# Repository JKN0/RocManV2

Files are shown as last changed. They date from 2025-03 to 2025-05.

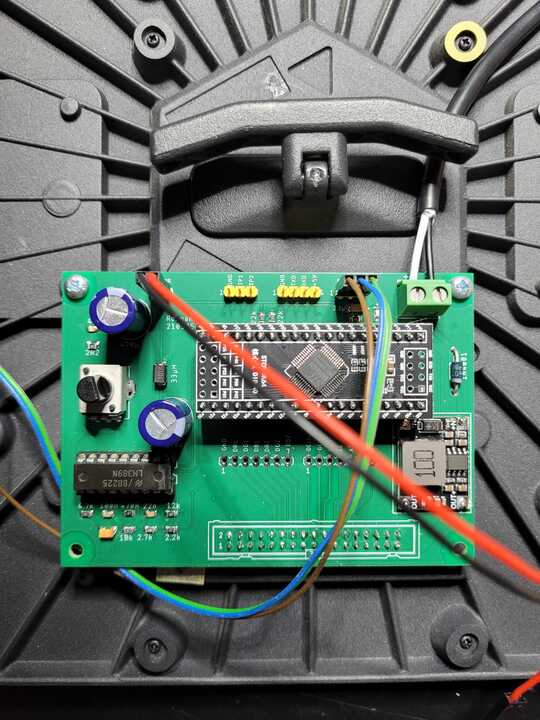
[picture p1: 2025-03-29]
RocManV2_PCB.jpg

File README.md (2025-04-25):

# RocMan V2

A Pacman game built using a junk RGB led matrix, 88x88 pixels

Controlled by junk IR remote

CPU is Chinese 8051 variant STC8A8K64D4

This is built on PCB, minor I/O-pin changes in SW compared to V1

There are two versions of PCB:
 - V2.0: original PCB
 - V2.1: connectors for USB/serial adapter and analog joystick added
 
Software is the same for both PCBs.

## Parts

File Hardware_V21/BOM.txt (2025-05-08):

Qty Value              Device             Package         Parts                Description                          
1   STC8A8K64D4-BRKOUT STC8A8K64D4-BRKOUT DIL40           IC1                  STC8A8K64D4/QFP48 @ DIP-40 breakout  
1                      LM389              DIL18           IC2                  Audio amp + 3 transistors            
1   1N4001             1N4004             DO41-10         D1                   DIODE
1   1N4148             1N4148             SOD-123         D2                   DIODE
1                      LEDCHIP-LED0805    CHIP-LED0805    LED1                 LED                                  0603
1                      ML34               ML34            CN1                  PIN HEADER FEMALE 2x17               
1                      MA04-1             MA04-1          CN2                  PIN HEADER 1x4                       
2                      MA03-1             MA03-1          CN3, CN4             PIN HEADER 1x3                       
1                      PINHD-1X2          1X02            CN5                  PIN HEADER 1x2                       
2                                                                              PIN HEADER FEMALE 1x20 (for IC1)     
1                      W237-02P           W237-132        CN6                  SREW CLAMP                           
2                      MA07-1             MA07-1          CN7, CN8             PIN HEADER 1x7                       
1                      MA06-1             MA06-1          CN9                  PIN HEADER 1x6                       
1                      MA05-1             MA05-1          CN10                 PIN HEADER 1x5                       
1   100n               C-EUC0805          C0805           C1                   CAPACITOR                            
1   22n                C-EUC0805          C0805           C2                   CAPACITOR                            
2   470μ               CPOL-EUE5-10.5     E5-10,5         C3, C4               POLARIZED CAPACITOR                  
1   2.2μ               CPOL-EUSMCA        SMC_A           C5                   POLARIZED CAPACITOR                  
1   1μ                 CPOL-EUSMCA        SMC_A           C6                   POLARIZED CAPACITOR                  
1   47n                C-EUC0805          C0805           C7                   CAPACITOR                            0603
1   10μ                CPOL-EUSMCA        SMC_A           C8                   POLARIZED CAPACITOR                  use 4.7μ
1   10k                R-EU_R0805         R0805           R1                   RESISTOR                             
1   2.7k               R-EU_R0805         R0805           R2                   RESISTOR                             
1   12k                R-EU_R0805         R0805           R3                   RESISTOR                             
1   4.7k               R-EU_R0805         R0805           R4                   RESISTOR                             
1   1k                 R-EU_R0805         R0805           R7                   RESISTOR                             
1   2R2                R-EU_R0805         R0805           R5                   RESISTOR                             
1   470R               R-EU_R0805         R0805           R6                   RESISTOR                             
1   2.2k               R-EU_R0805         R0805           R8                   RESISTOR                             
2   22k                R-EU_R0805         R0805           R9, R10              RESISTOR
1   100R               R-EU_R0805         R0805           R11                  RESISTOR                             
1   10k                PTV09A-4015F-A103  PTV09A4015FA103 VR1                  Pot 10K AUDIO 20%                    
1   33μH               L-USL4532C         L4532M          L1                   INDUCTOR                     100μH works also
1                      Pwr supply module                                       Pwr 9...24V/5V                       
1   TSOP34838          IR receiver                                                                                  
1                      18-pin IC socket                                        Socket for IC2
1   PCB

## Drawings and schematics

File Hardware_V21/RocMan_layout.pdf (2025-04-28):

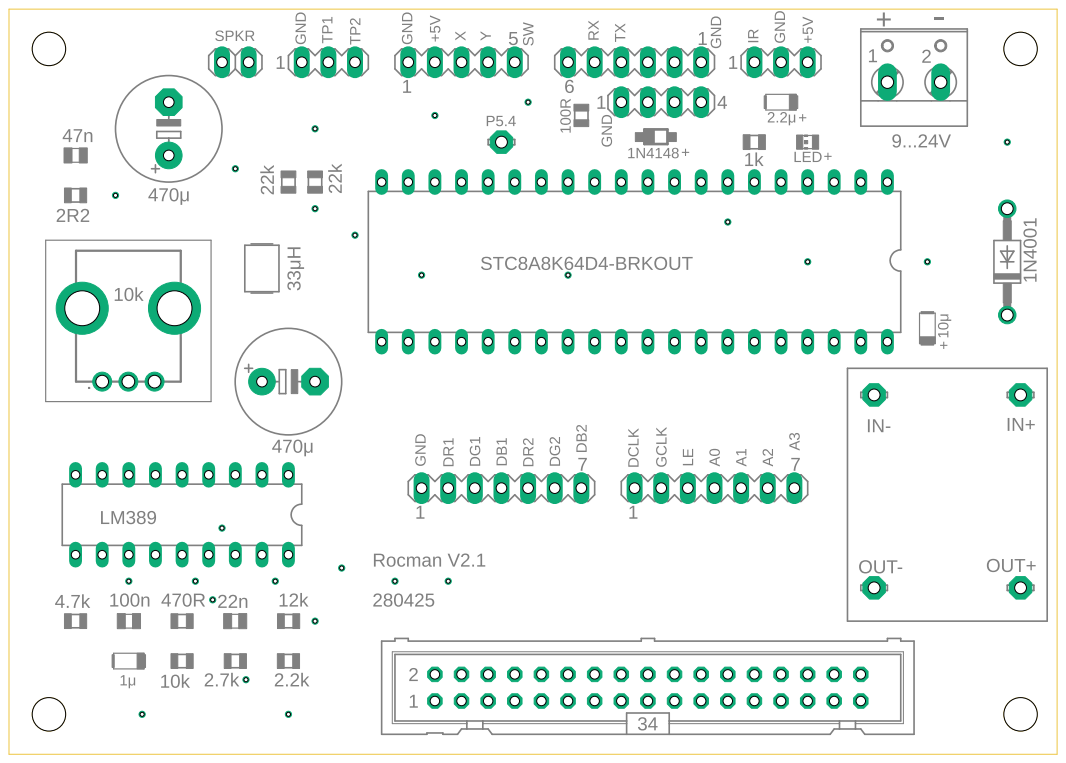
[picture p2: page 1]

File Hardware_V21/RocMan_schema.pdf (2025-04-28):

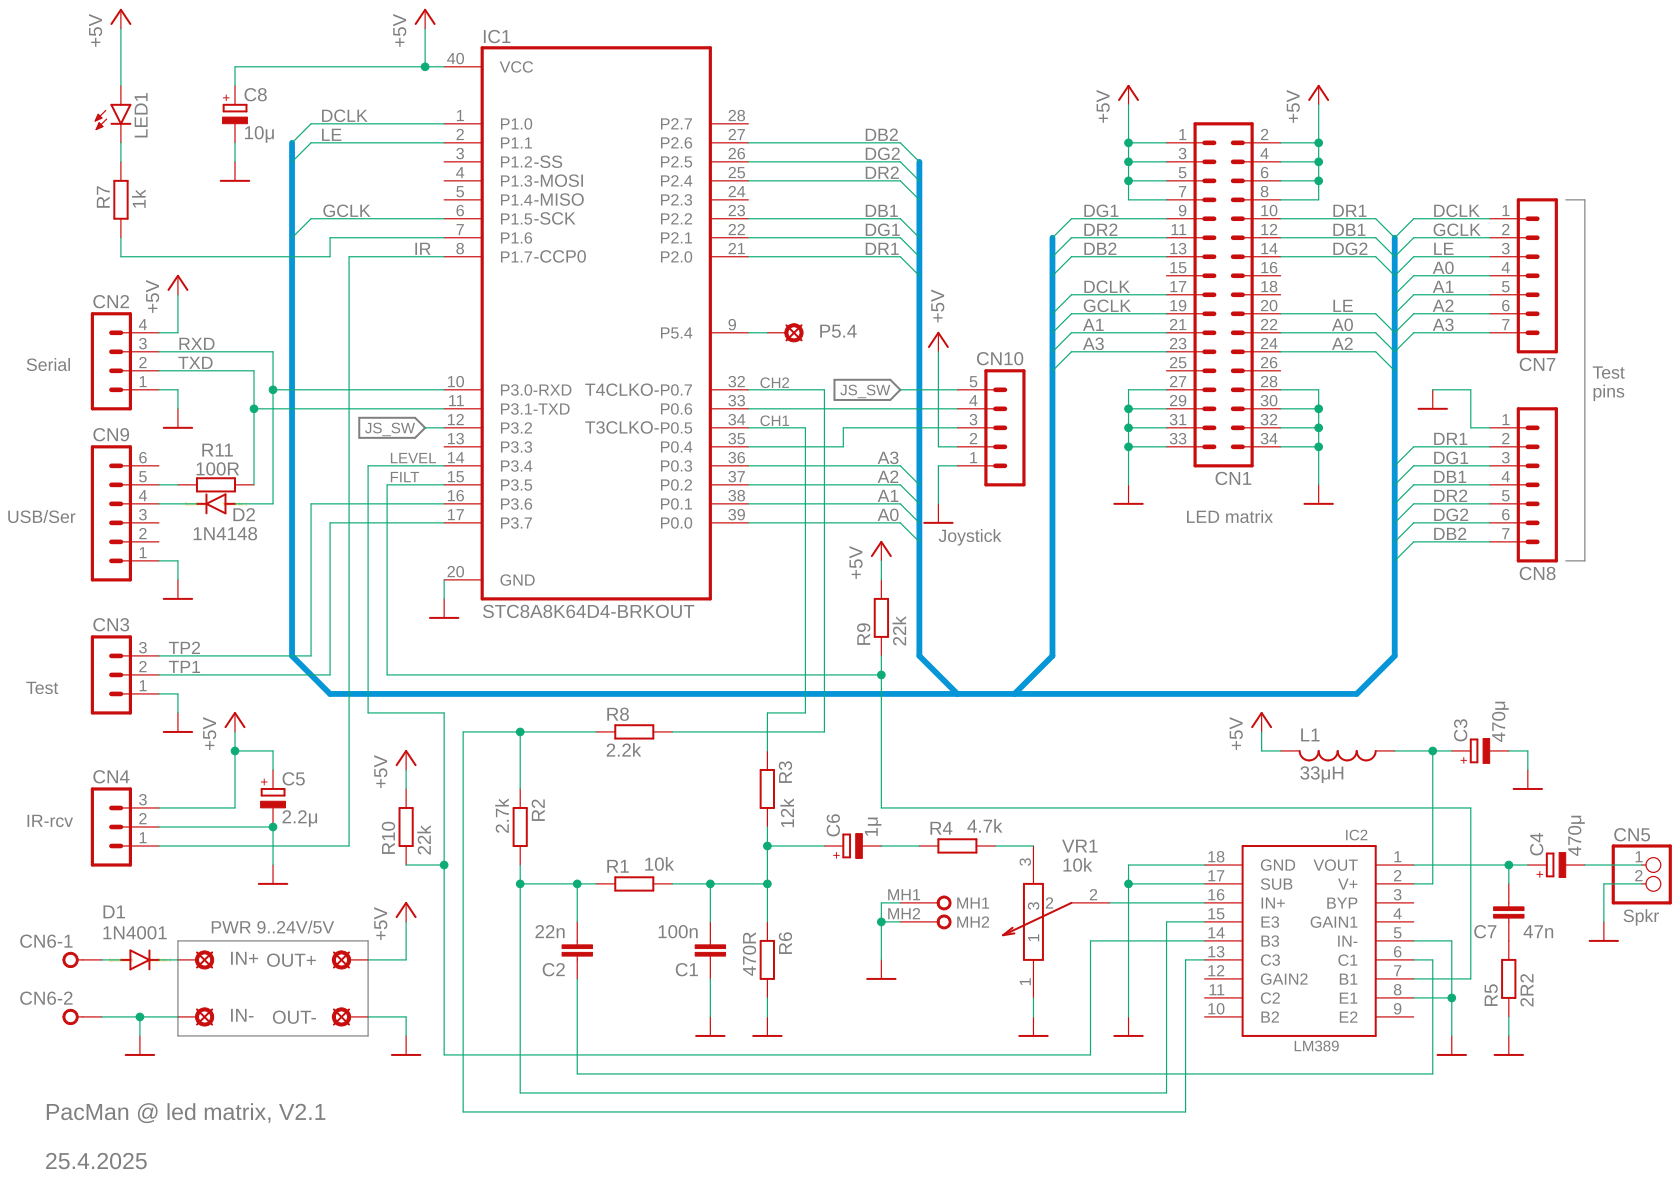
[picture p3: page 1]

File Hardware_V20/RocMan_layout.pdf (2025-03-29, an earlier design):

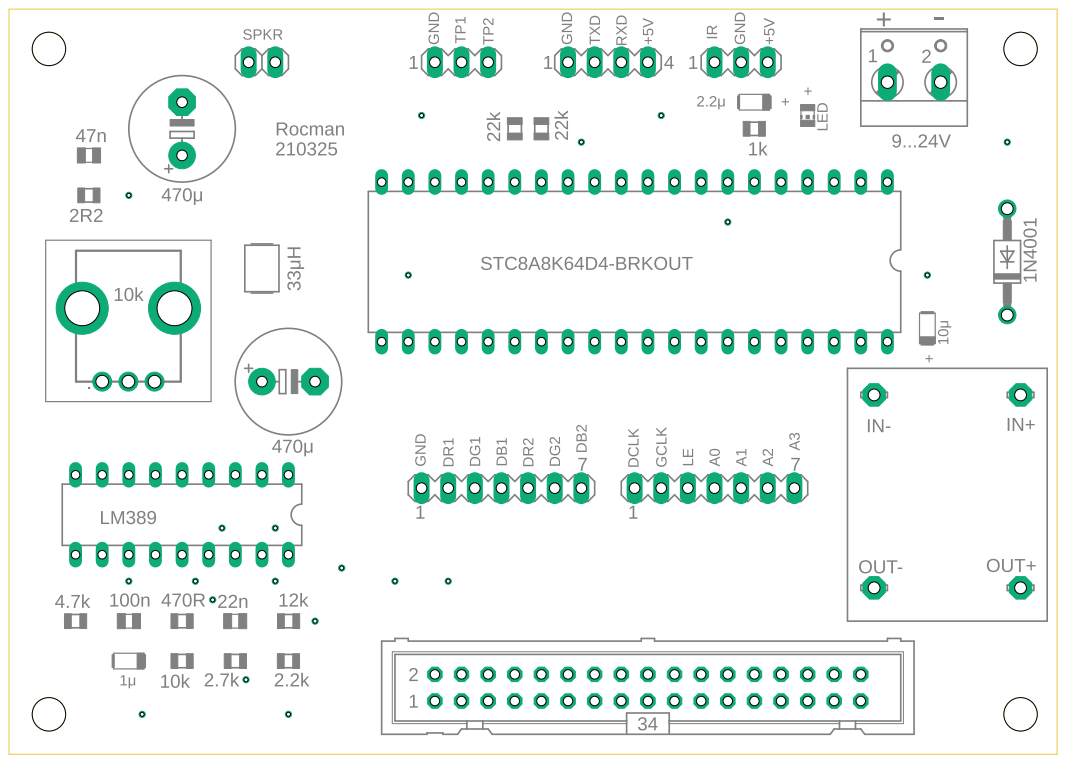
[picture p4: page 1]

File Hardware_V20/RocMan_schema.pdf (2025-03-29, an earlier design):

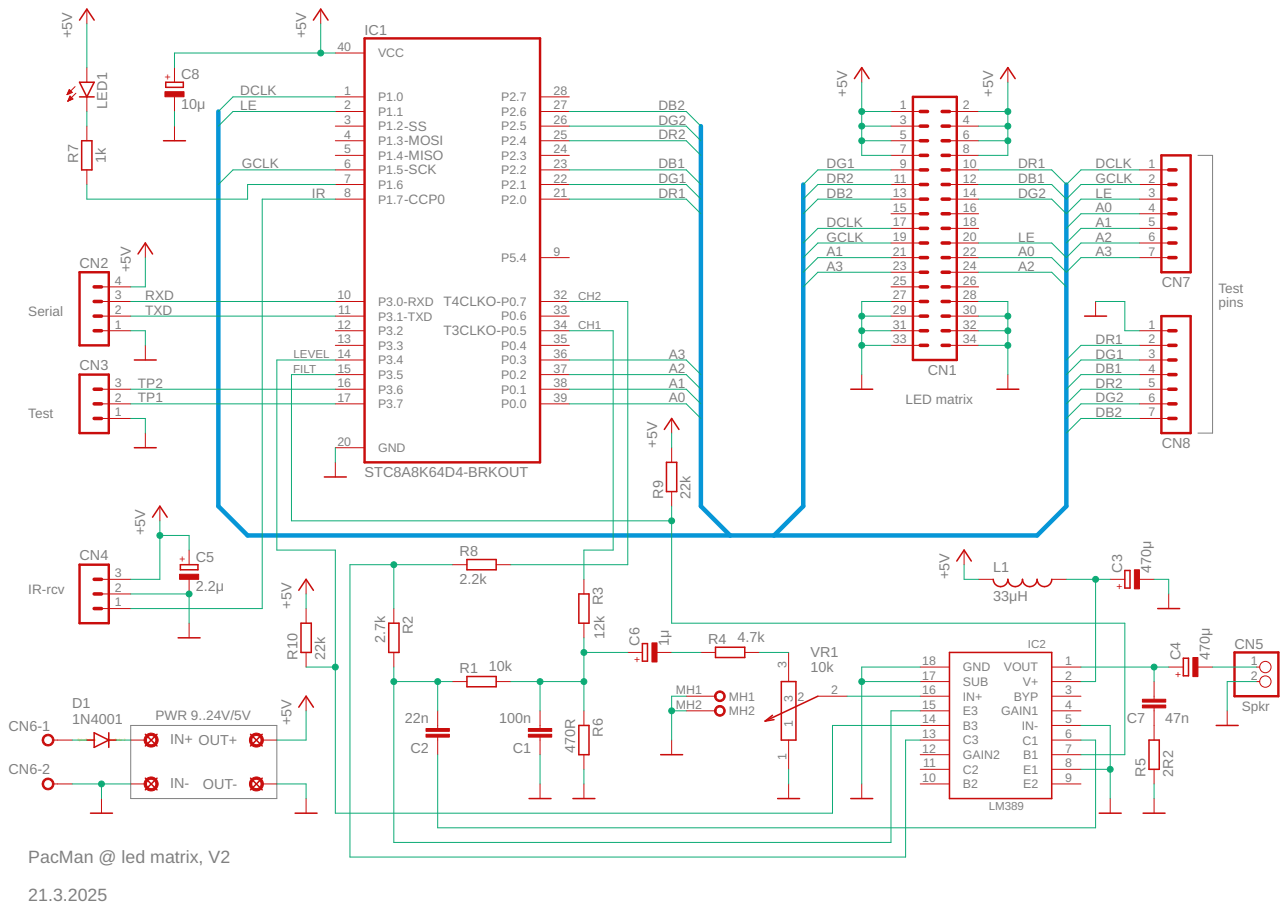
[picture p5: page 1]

2 TXD | 11 | 33 34 CH1
1 | 12 LEVEL

2 TP1
1 | 20

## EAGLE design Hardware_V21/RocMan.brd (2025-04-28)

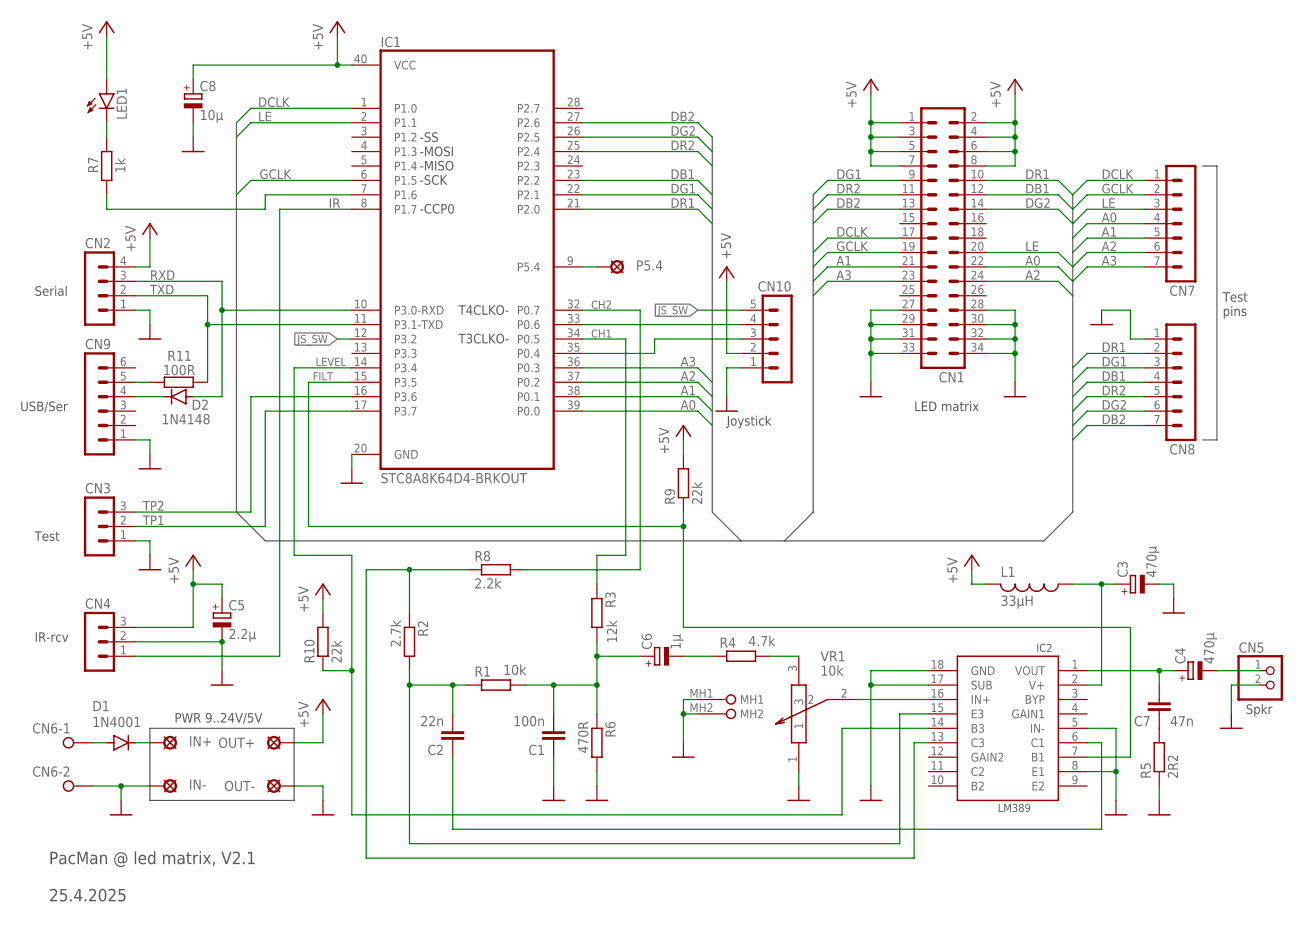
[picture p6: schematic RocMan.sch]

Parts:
C1: 100n; C0805
C2: 22n; C0805
C3, C4: 470μ; E5-10,5
C5: 2.2μ; SMC_A
C6: 1μ; SMC_A
C7: 47n; C0805
C8: 10μ; SMC_A
CN1: ML34
CN2: MA04-1
CN3, CN4: MA03-1
CN5: PINHD-1X2; 1X02
CN6: W237-02P; W237-132
CN7, CN8: MA07-1
CN9: MA06-1
CN10: MA05-1
D1: 1N4001; DO41-10
D2: 1N4148; SOD123
IC1: STC8A8K64D4-BRKOUT; DIL40
IC2: LM389; DIL18
IN+: LSP11
IN-: LSP11
L1: 33μH; L4532M
LED1: LEDCHIP-LED0805; CHIP-LED0805
OUT+: LSP11
OUT-: LSP11
P5.4: LSP11
R1: 10k; R0805
R2: 2.7k; R0805
R3: 12k; R0805
R4: 4.7k; R0805
R5: 2R2; R0805
R6: 470R; R0805
R7: 1k; R0805
R8: 2.2k; R0805
R9, R10: 22k; R0805
R11: 100R; R0805
VR1: 10k; PTV09A4015FA103

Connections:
+5V: C5.+, C8.+, CN1.1, CN1.2, CN1.3, CN1.4, CN1.5, CN1.6, CN1.7, CN1.8, CN2.4, CN4.3, CN10.2, IC1.40 (VCC), L1.2, LED1.A, OUT+.MP, R9.2, R10.2
A0: CN1.22, CN7.4, IC1.39 (P0.0)
A1: CN1.21, CN7.5, IC1.38 (P0.1)
A2: CN1.24, CN7.6, IC1.37 (P0.2)
A3: CN1.23, CN7.7, IC1.36 (P0.3)
CH1: IC1.34 (P0.5), R3.1
CH2: IC1.32 (P0.7), R8.2
DB1: CN1.12, CN8.4, IC1.23 (P2.2)
DB2: CN1.13, CN8.7, IC1.27 (P2.6)
DCLK: CN1.17, CN7.1, IC1.1 (P1.0)
DG1: CN1.9, CN8.3, IC1.22 (P2.1)
DG2: CN1.14, CN8.6, IC1.26 (P2.5)
DR1: CN1.10, CN8.2, IC1.21 (P2.0)
DR2: CN1.11, CN8.5, IC1.25 (P2.4)
FILT: IC1.15 (P3.5), IC2.7 (B1), R9.1
GCLK: CN1.19, CN7.2, IC1.6 (P1.5)
GND: C1.1, C3.-, C5.-, C8.-, CN1.27, CN1.28, CN1.29, CN1.30, CN1.31, CN1.32, CN1.33, CN1.34, CN2.1, CN3.1, CN4.2, CN5.2, CN6.2, CN8.1, CN9.1, CN10.1, IC1.20 (GND), IC2.5 (IN-), IC2.8 (E1), IC2.17 (SUB), IC2.18 (GND), IN-.MP, OUT-.MP, R5.1, R6.2, VR1.1, VR1.MH1, VR1.MH2
IR: CN4.1, IC1.8 (P1.7)
JS_SW: CN10.5, IC1.12 (P3.2)
LE: CN1.20, CN7.3, IC1.2 (P1.1)
LEVEL: IC1.14 (P3.4), IC2.14 (B3), R10.1
unnamed: C2.2, IC2.15 (E3), R1.1, R2.2
unnamed: C1.2, C6.+, R1.2, R3.2, R6.1
unnamed: C2.1, IC2.6 (C1)
unnamed: C6.-, R4.1
unnamed: R4.2, VR1.3
unnamed: IC2.13 (C3), R2.1, R8.1
unnamed: IC2.16 (IN+), VR1.2
unnamed: C3.+, IC2.2 (V+), L1.1
unnamed: CN6.1, D1.A
unnamed: C4.+, C7.2, IC2.1 (VOUT)
unnamed: C4.-, CN5.1
unnamed: D1.C, IN+.MP
unnamed: C7.1, R5.2
unnamed: IC1.7 (P1.6), R7.1
unnamed: LED1.C, R7.2
unnamed: CN9.5, R11.1
unnamed: CN9.4, D2.C
unnamed: CN10.4, IC1.33 (P0.6)
unnamed: CN10.3, IC1.35 (P0.4)
unnamed: IC1.9 (P5.4), P5.4.MP
RXD: CN2.3, D2.A, IC1.10 (P3.0-RXD)
TP1: CN3.2, IC1.17 (P3.7)
TP2: CN3.3, IC1.16 (P3.6)
TXD: CN2.2, IC1.11 (P3.1-TXD), R11.2

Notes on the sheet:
-SS -MOSI -MISO -SCK
-CCP0
Serial
Test
T4CLKO- T3CLKO-
IR-rcv
Spkr
PacMan @ led matrix, V2.1 25.4.2025
LED matrix
PWR 9..24V/5V
Test pins
USB/Ser
Joystick

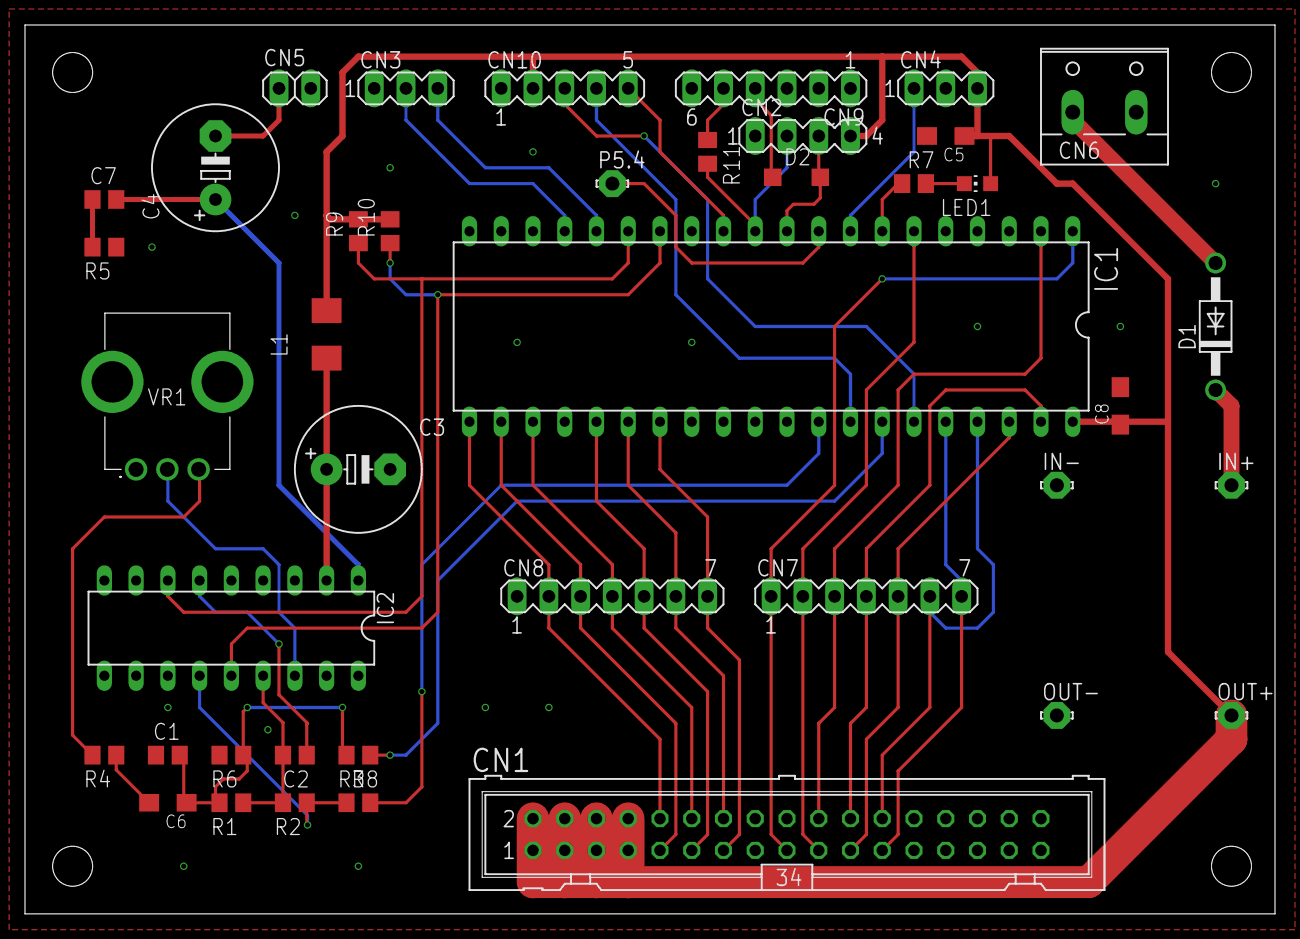
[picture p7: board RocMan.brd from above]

Board: 2 copper layers, 100.0 x 71.1 mm, 41 parts (0 on the bottom side), 45 nets.

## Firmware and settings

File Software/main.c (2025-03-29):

/***************************************************************************
 
 main.c
 
 RocMan - PacMan for junk led matrix

 Controller: STC8A8K64D4 @ breakout
 
 12.12.2024  - First version
 26.03.2025  - PCB version

 ***************************************************************************/

/* --------------------------------------------------------------------------
 
 CPU I/O-devices used:
 
   Timers:
     T0 = RTC, 5 ms
     T1 = UART1 baud rate 115,2 kbps
     T2 = -
     T3 = sound ch1
     T4 = sound ch2
   
   UARTs:
     UART1 = serial UI + debug
     UART2...4 = -
     
   PCA:
     CH0,CH1 = IR-code receiving
     CH2,CH3 = -
     
   SPI:
     SCK = matrix GCLK pulses at 2.8 MHz (MISO/MOSI not connected)
     
   DMA:
     transfer 32 random bytes via SPI to get 256 SCK pulses
     
 Software timer usage:
 
   Timer 1 = heartbeat led, 1 Hz
   Timer 2 = frame sending timings in matrix task
   Timer 3 = ghost state management timings in game task
   Timer 4 = game mode management timings in game task

   Auto-repeat timer 1 = fast rate tick generation for game task (pacman)
   Auto-repeat timer 2 = medium rate tick generation for game task (normal ghosts)
   Auto-repeat timer 3 = slow rate tick generation for game task (slow ghosts)
   
---------------------------------------------------------------------------- */

#define __STC8__

#include <stdlib.h>
#include <stdio.h>
#include <string.h>
#include <datatypes.h>
#include "stc8a8.h"
#include "main.h"
#include "matrix.h"
#include "game.h"
#include "sound.h"
#include "ir_rec.h"

/* =====================================================================
------------------------ Constants & macros ------------------------- */

// sysclock 45 MHz, cycle 22 ns
// T0x12=0
// Timer 0 counts sysclock/12 = 3.75 MHz, reload for 5 ms = 18750
#define TMR0_RELOAD         (WORD)(-18750)

// UART baudrate = 65536 - FOSC/rate/4,  T1x12=1
// 45MHz/115200/4 = 98
#define TMR1_RELOAD         (WORD)(-98)    // 115.2 kbit/s @ 45 MHz

#define TESTCLEAR(s,d)      if (s) {s=0; d=1;} else d=0;
#define CYCLIC_INC(p)       { p++; if (p >= (outbuf+OUTBUF_LEN)) p = outbuf; }

/* =======================================================================
------------------------ I/O ------------------------------------------ */

#define run_led              P1_6       // heartbeat-led

/* =====================================================================
------------------------ Structures --------------------------------- */

/* =====================================================================
------------------------  Global variables  ------------------------- */

BYTE timeout_ctr1;
BYTE timeout_ctr2;
WORD timeout_ctr3;
WORD timeout_ctr4;

BYTE rep_timeout_ctr1;
BYTE rep_timeout_value1;
BYTE rep_timeout_ctr2;
BYTE rep_timeout_value2;
BYTE rep_timeout_ctr3;
BYTE rep_timeout_value3;

BIT volatile timeout1;
BIT volatile timeout2;
BIT volatile timeout3;
BIT volatile timeout4;

BIT volatile rep_timeout1;
BIT volatile rep_timeout2;
BIT volatile rep_timeout3;

BIT volatile rtc_flag;
BIT tick = FALSE;

BIT cr_received = FALSE;
BIT tx_on = FALSE;

XDATA BYTE inbuf[INBUF_LEN];

XDATA BYTE outbuf[OUTBUF_LEN];
XDATA BYTE *outbuf_top = outbuf;
XDATA BYTE *outbuf_bot = outbuf;
BIT outbuf_full = FALSE;

/* =====================================================================
------------------------ Function prototypes ------------------------ */

void init_hw( void );

/* =====================================================================
Main
--------------------------------------------------------------------- */

void main( void )
{
    init_hw();
    init_matrix_task();
    init_game_task();

    ENABLE(EA);          // Enable interrupts
    
    printf_fast("\r\n*** RocMan ***\r\n");
    
    set_timeout1(TIME_100MS);

    TP = 0;
    
    /* --- Main loop --- */
    while (TRUE) 
    {
        // Copy the rtc_flag (set by RTC interrupt) to tick-flag in one atomic operation.
        // This makes sure the tick won't change during the main loop.
        TESTCLEAR(rtc_flag,tick);

        // Run tasks
        matrix_task();
        game_task();
        sound_task();
        ir_task();
        serial_rx_task();
        
        // Hearbeat led
        if (timeout1)
        {
            run_led = !run_led;
            set_timeout1(TIME_500MS);
        }

        // tick-flag valid only for one main loop iteration 
        tick = FALSE;
    }
}

/* =======================================================================
Start timeout 1
----------------------------------------------------------------------- */

void set_timeout1( BYTE delay )
{
    DISABLE(ET0);
    timeout1 = FALSE;
    timeout_ctr1 = delay;
    ENABLE(ET0);
}

/* =======================================================================
Start timeout 2
----------------------------------------------------------------------- */

void set_timeout2( BYTE delay )
{
    DISABLE(ET0);
    timeout2 = FALSE;
    timeout_ctr2 = delay;
    ENABLE(ET0);
}

/* =======================================================================
Start timeout 3
----------------------------------------------------------------------- */

void set_timeout3( WORD delay )
{
    DISABLE(ET0);
    timeout3 = FALSE;
    timeout_ctr3 = delay;
    ENABLE(ET0);
}

/* =======================================================================
Start timeout 4
----------------------------------------------------------------------- */

void set_timeout4( WORD delay )
{
    DISABLE(ET0);
    timeout4 = FALSE;
    timeout_ctr4 = delay;
    ENABLE(ET0);
}

/* =======================================================================
Start auto-repeating timeout 1
----------------------------------------------------------------------- */

void set_rep_timeout1( BYTE delay )
{
    DISABLE(ET0);
    rep_timeout1 = FALSE;
    rep_timeout_ctr1 = delay;
    rep_timeout_value1 = delay;
    ENABLE(ET0);
}

/* =======================================================================
Start auto-repeating timeout 2
----------------------------------------------------------------------- */

void set_rep_timeout2( BYTE delay )
{
    DISABLE(ET0);
    rep_timeout2 = FALSE;
    rep_timeout_ctr2 = delay;
    rep_timeout_value2 = delay;
    ENABLE(ET0);
}

/* =======================================================================
Start auto-repeating timeout 3
----------------------------------------------------------------------- */

void set_rep_timeout3( BYTE delay )
{
    DISABLE(ET0);
    rep_timeout3 = FALSE;
    rep_timeout_ctr3 = delay;
    rep_timeout_value3 = delay;
    ENABLE(ET0);
}

/* =======================================================================
putchar. printf_fast() calls this.
----------------------------------------------------------------------- */

int putchar( int ch )
{
    DISABLE(ES);
    
    if (!outbuf_full)
    {
        *outbuf_top = ch;

        CYCLIC_INC(outbuf_top);
        if (outbuf_bot == outbuf_top)
            outbuf_full = TRUE;

        if (!tx_on)
        {
            tx_on = TRUE;
            TI = 1;
        }
    }
    
    ENABLE(ES);

    return ch;
}

/* =======================================================================
putch_intr. putchar() to be called from the serial interrupt.
----------------------------------------------------------------------- */

void putch_intr( BYTE ch ) __using (1) 
{
    if (!outbuf_full)
    {
        *outbuf_top = ch;

        CYCLIC_INC(outbuf_top);
        if (outbuf_bot == outbuf_top)
            outbuf_full = TRUE;

        if (!tx_on)
        {
            tx_on = TRUE;
            TI = 1;
        }
    }
}

/* =======================================================================
Init hardware
----------------------------------------------------------------------- */

void init_hw( void )
{
    EN_XSFR();          // Enable extended SFRs
    
    // Clock: 45 MHz
    
    // -- Ports
    // Pinmode-macros cause warnings 'unreachable code': ignore them
    #pragma save
    #pragma disable_warning 126
    P1_pinmode(OPENDRAIN,B6);               // led
    P3_pinmode(PUSHPULL,B7|B6);             // TP,TP2
    P1_pinmode(PUSHPULL,B5|B4|B3|B1|B0);    // SPI pins
    P0_pinmode(PUSHPULL,ALL);               // addr,T3CLKO,T4CLKO
    P2_pinmode(PUSHPULL,ALL);               // RGB
    P3_pinmode(OPENDRAIN,B5|B4);            // CH2_FILTER,CH2_LEVEL
    #pragma restore
    P3_4 = 0;                               // CH2_LEVEL = low level
    P3_5 = 1;                               // CH2_FILTER = on
    
    // -- Timers
    AUXR = T1x12;       // T0x12=0, T1x12=1
    AUXR &= ~S1ST2;     // S1ST2=0 (select T1 as baud rate generator)
    
    TMOD = 0x00;        // Tmr 0 = mode 0, timer; Tmr 1 = mode 0, timer
                        // Note: mode 0 = 16-bit auto-reload in STC8
    TCON = 0x00;        // IEx = 0, TRx = 0, TFx = 0
    
    // Timer 0: RTC
    TMR0 = TMR0_RELOAD;
    TR0 = 1;

    // Timer 1: baud rate generator
    TMR1 = TMR1_RELOAD;
    TR1 = 1;
    
    // Timer 3 & 4: sound generators
    T4T3M = T3CLKO | T4CLKO;    // enable freq output

    // -- UART
    SM1 = 1;            // Mode 1
    REN = 1;            // Receive enable
    
    // -- PCA   
    CMOD = 0x00;        // internal clock, Fosc/12 = 3.75 MHz
    CCON = 0x00;        // all interrupts off
    CCAPM0 = 0x11;      // channel 0: capture neg edge, interrupt enabled
    CCAPM1 = 0x48;      // channel 1: software timer, interrupt disabled
    CR = 1;             // PCA run
 
    // -- SPI
    SPDAT = 0;                             // initial SPI data
    SPSTAT = SPIF | WCOL;                  // clear SPIF and WCOL
    SPCTL = SPEN | MSTR | SSIG | SPR1;     // master mode, ignore SS, clk 2.8 MHz
    
    // -- DMA: SPI send
    DMA_SPI_CFG = ACT_TX;                  // DMA transmits via SPI
    DMA_SPI_STA = 0;
    
    // -- EEPROM
    IAP_TPS = 45;   // clk = 45 MHz
    
    // -- Interrupts
    // Enable: Tmr0, UART1, DMA SPI
    // Note: in STC8 there is no separate EC (enable PCA) bit, just ECF and ECCFx directly
    ENABLE(ET0);    
    ENABLE(ES);
    DMA_SPI_CFG |= SPIIE | SPIIP1;         // DMA int prio 1

}

/* ======================================================================= */
/* =====================       INTERRUPT SERVICES     ==================== */
/* ======================================================================= */

/* =======================================================================
Real time interrupt: Timer 0, 5 ms interval 

Run the timeouts.
----------------------------------------------------------------------- */

void rtc_isr(void) __interrupt(TF0_VECTOR) __using (1) 
{
    static BIT rtc_toggle = FALSE;
    
    // Auto reload, no need to reload TMR0

    /*
     * --- Timers ---
     */
     
    // Decrement timeout counters and set the flag, if counter == 0
    timeout_ctr1--;
    if (timeout_ctr1 == 0)
        timeout1 = TRUE;
        
    timeout_ctr2--;
    if (timeout_ctr2 == 0)
        timeout2 = TRUE;
        
    timeout_ctr3--;
    if (timeout_ctr3 == 0)
        timeout3 = TRUE;
    
    timeout_ctr4--;
    if (timeout_ctr4 == 0)
        timeout4 = TRUE;
    
    rep_timeout_ctr1--;
    if (rep_timeout_ctr1 == 0)
    {
        rep_timeout1 = TRUE;
        rep_timeout_ctr1 = rep_timeout_value1;
    }

    rep_timeout_ctr2--;
    if (rep_timeout_ctr2 == 0)
    {
        rep_timeout2 = TRUE;
        rep_timeout_ctr2 = rep_timeout_value2;
    }

    rep_timeout_ctr3--;
    if (rep_timeout_ctr3 == 0)
    {
        rep_timeout3 = TRUE;
        rep_timeout_ctr3 = rep_timeout_value3;
    }

    // Set the rtc_flag every 10 ms 
    rtc_toggle = !rtc_toggle;
    if (rtc_toggle)
        rtc_flag = TRUE;
}

/* =======================================================================
Serial interrupt
----------------------------------------------------------------------- */

void serial_isr(void) __interrupt(UART1_VECTOR) __using (1) 
{
    static BYTE idx = 0;
    BYTE ch;

    // --- UART receive
    if (RI)
    {
        RI = 0;
        
        ch = SBUF & 0x7F; 

        if (ch == '\r')                 // if CR -> line ready
        {
            inbuf[idx] = '\0';
            idx = 0;

            putch_intr('\r');              // echo CR
            putch_intr('\n');

            cr_received = TRUE;         // full line received
        }
        else if (ch == '\b' && idx > 0) // if BS -> remove char from buf
        {
            idx--;
            putch_intr('\b');              // echo BS
            putch_intr(' ');
            putch_intr('\b');
        }
        else if (ch >= ' ')             // normal char
        {
            ch |= 0x20;                 // to lowercase

            if (idx < INBUF_LEN-1)      // to buf, if fits
            {
                inbuf[idx] = ch;
                idx++;

                putch_intr(ch);          // echo
           }
        }
    }

    // --- UART send
    if (TI)
    {
        TI = 0;
        
        // Anything to send?
        if (outbuf_bot != outbuf_top || outbuf_full)
        {
            SBUF = *outbuf_bot;          // Transmit the character
            CYCLIC_INC(outbuf_bot);
            outbuf_full = FALSE;
        }
        else
            tx_on = FALSE;
    }
}

/* =======================================================================
----------------------------------------------------------------------- */

unsigned char __sdcc_external_startup(void)
{
    return 0;
}

/* ============================ EOF ====================================== */

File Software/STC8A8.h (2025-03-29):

/*-------------------------------------------------------------------------
 STC8A8.h
 
 H-file for STC8A8K64D4 etc.
-------------------------------------------------------------------------*/

#ifndef _STC8A8_H
#define _STC8A8_H

#include <8051.h>
#include <compiler.h>

#ifdef REG8051_H
#undef REG8051_H
#endif

// --- AUXR -------------------------------------------------------------------------------------

SFR(AUXR,0x8E);
#define T0x12     0x80    // AUXR.7
#define T1x12     0x40    // AUXR.6
#define UART_M0x6 0x20    // AUXR.5
#define T2R       0x10    // AUXR.4
#define T2_CT     0x08    // AUXR.3
#define T2x12     0x04    // AUXR.2
#define EXTRAM    0x02    // AUXR.1
#define S1ST2     0x01    // AUXR.0

// --- Pin switch -------------------------------------------------------------------------------------

SFR(P_SW1,0xA2);
#define S1_S1     0x80    // P_SW1.7
#define S1_S0     0x40    // P_SW1.6
#define CCP_S1    0x20    // P_SW1.5
#define CCP_S0    0x10    // P_SW1.4
#define SPI_S1    0x08    // P_SW1.3
#define SPI_S0    0x04    // P_SW1.2

SFR(P_SW2,0xBA);
#define EAXFR     0x80    // P_SW2.7
#define I2C_S1    0x20    // P_SW2.5
#define I2C_S0    0x10    // P_SW2.4
#define CMPO_S    0x08    // P_SW2.3
#define S4_S      0x04    // P_SW2.2
#define S3_S      0x02    // P_SW2.1
#define S2_S      0x01    // P_SW2.0

// --- Interrupts -------------------------------------------------------------------------------------

// IE deviations
SBIT(EADC, 0xA8, 5);    // normally ET2
SBIT(ELVD, 0xA8, 6);    // normally EC

// IE2
SFR(IE2,0xAF);
#define ET4     0x40    // IE2.6
#define ET3     0x20    // IE2.5
#define ES4     0x10    // IE2.4
#define ES3     0x08    // IE2.3
#define ET2     0x04    // IE2.2
#define ESPI    0x02    // IE2.1
#define ES2     0x01    // IE2.0

// INTCLKO
SFR(INTCLKO,0x8F);
#define EX4     0x40    // INTCLKO.6
#define EX3     0x20    // INTCLKO.5
#define EX2     0x10    // INTCLKO.4
#define T2CLKO  0x04    // INTCLKO.2
#define T1CLKO  0x02    // INTCLKO.1
#define T0CLKO  0x01    // INTCLKO.0

// IP deviations
SBIT(PADC, 0xB8, 5);    // normally PT2
SBIT(PLVD, 0xB8, 6);    // normally PPC
SBIT(PPCA, 0xB8, 7);

SFR(AUXINTIF,0xEF); 
#define INT4IF  0x40    // AUXINTIF.6
#define INT3IF  0x20    // AUXINTIF.5
#define INT2IF  0x10    // AUXINTIF.4
#define T4IF    0x04    // AUXINTIF.2
#define T3IF    0x02    // AUXINTIF.1
#define T2IF    0x01    // AUXINTIF.0


// IPH
SFR(IPH,0xB7);
#define PPCAH   0x80    // IPH.7
#define PLVDH   0x40    // IPH.6
#define PADCH   0x20    // IPH.5
#define PSH     0x10    // IPH.4
#define PT1H    0x08    // IPH.3
#define PX1H    0x04    // IPH.2
#define PT0H    0x02    // IPH.1
#define PX0H    0x01    // IPH.0

// IP2
SFR(IP2,0xB5);
#define PI2C    0x40    // IP2.6
#define PCMP    0x20    // IP2.5
#define PX4     0x10    // IP2.4
#define PPWMFD  0x08    // IP2.3
#define PPWM    0x04    // IP2.2
#define PSPI    0x02    // IP2.1
#define PS2     0x01    // IP2.0

// IP2H
SFR(IP2H ,0xB6);
#define PI2CH   0x40    // IP2H.6
#define PCMPH   0x20    // IP2H.5
#define PX4H    0x10    // IP2H.4
#define PPWMFDH 0x08    // IP2H.3
#define PPWMH   0x04    // IP2H.2
#define PSPIH   0x02    // IP2H.1
#define PS2H    0x01    // IP2H.0

// IP3
SFR(IP3,0xDF); 
#define PS4     0x02    // IP3.1
#define PS3     0x01    // IP3.0

// IP3H
SFR(IP3H,0xEE);
#define PS4H    0x02    // IP3H.1
#define PS3H    0x01    // IP3H.0

#define P0INTE         (*(unsigned char volatile __xdata *)0xFD00)
#define P1INTE         (*(unsigned char volatile __xdata *)0xFD01)
#define P2INTE         (*(unsigned char volatile __xdata *)0xFD02)
#define P3INTE         (*(unsigned char volatile __xdata *)0xFD03)
#define P4INTE         (*(unsigned char volatile __xdata *)0xFD04)
#define P5INTE         (*(unsigned char volatile __xdata *)0xFD05)
#define P6INTE         (*(unsigned char volatile __xdata *)0xFD06)
#define P7INTE         (*(unsigned char volatile __xdata *)0xFD07)

#define P0INTF         (*(unsigned char volatile __xdata *)0xFD10)
#define P1INTF         (*(unsigned char volatile __xdata *)0xFD11)
#define P2INTF         (*(unsigned char volatile __xdata *)0xFD12)
#define P3INTF         (*(unsigned char volatile __xdata *)0xFD13)
#define P4INTF         (*(unsigned char volatile __xdata *)0xFD14)
#define P5INTF         (*(unsigned char volatile __xdata *)0xFD15)
#define P6INTF         (*(unsigned char volatile __xdata *)0xFD16)
#define P7INTF         (*(unsigned char volatile __xdata *)0xFD17)

// TODO: similar macros than for I/O modes
// IM1,IM0:
//   0,0 = falling edge
//   0,1 = rising edge
//   1,0 = low level
//   1,1 = high level

#define P0IM0          (*(unsigned char volatile __xdata *)0xFD20)
#define P1IM0          (*(unsigned char volatile __xdata *)0xFD21)
#define P2IM0          (*(unsigned char volatile __xdata *)0xFD22)
#define P3IM0          (*(unsigned char volatile __xdata *)0xFD23)
#define P4IM0          (*(unsigned char volatile __xdata *)0xFD24)
#define P5IM0          (*(unsigned char volatile __xdata *)0xFD25)
#define P6IM0          (*(unsigned char volatile __xdata *)0xFD26)
#define P7IM0          (*(unsigned char volatile __xdata *)0xFD27)

#define P0IM1          (*(unsigned char volatile __xdata *)0xFD30)
#define P1IM1          (*(unsigned char volatile __xdata *)0xFD31)
#define P2IM1          (*(unsigned char volatile __xdata *)0xFD32)
#define P3IM1          (*(unsigned char volatile __xdata *)0xFD33)
#define P4IM1          (*(unsigned char volatile __xdata *)0xFD34)
#define P5IM1          (*(unsigned char volatile __xdata *)0xFD35)
#define P6IM1          (*(unsigned char volatile __xdata *)0xFD36)
#define P7IM1          (*(unsigned char volatile __xdata *)0xFD37)

#define PINIPL         (*(unsigned char volatile __xdata *)0xFD60)
#define PINIPH         (*(unsigned char volatile __xdata *)0xFD61)

#define P0WKUE         (*(unsigned char volatile __xdata *)0xFD40)
#define P1WKUE         (*(unsigned char volatile __xdata *)0xFD41)
#define P2WKUE         (*(unsigned char volatile __xdata *)0xFD42)
#define P3WKUE         (*(unsigned char volatile __xdata *)0xFD43)
#define P4WKUE         (*(unsigned char volatile __xdata *)0xFD44)
#define P5WKUE         (*(unsigned char volatile __xdata *)0xFD45)
#define P6WKUE         (*(unsigned char volatile __xdata *)0xFD46)
#define P7WKUE         (*(unsigned char volatile __xdata *)0xFD47)

// --- I/O ports --------------------------------------------------------------------------------------

// Macros for port I/O modes

// PxM1,PxM0: 
//   0,0 -> quasi bd
//   0,1 -> push-pull
//   1,0 -> input (default)
//   1,1 -> open drain

#define B0   0x01
#define B1   0x02
#define B2   0x04
#define B3   0x08
#define B4   0x10
#define B5   0x20
#define B6   0x40
#define B7   0x80
#define ALL  0xFF

#define QUASIBD   0
#define PUSHPULL  1
#define INPUT     2
#define OPENDRAIN 3
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

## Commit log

2025-03-29 Pacman on junk led matrix & 8051
    [RocMan.brd, RocMan.sch]
2025-04-11 Add support for couple of junk IR remotes
2025-04-16 Added BOM
2025-04-25 Added V2.1 schema
    [RocMan.brd, RocMan.sch]
2025-04-28 Final V2.1 HW
    [RocMan.brd, RocMan.sch]
